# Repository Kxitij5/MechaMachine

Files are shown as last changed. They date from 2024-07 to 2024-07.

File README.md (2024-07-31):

# MechaMachine
## A real-time face tracking turret inspired by KillJoy, a character in the video game called Valorant.

A face tracking turret which tracks the faces of the people and aims for headshot. There are 2 versions of this project, one which uses open-cv and a python package built upon it, known as cvzone; the other one is a custom trained YOLOv5 model which differentiates between friend and enemy before shooting.

## Table Of Content
- [Installation](#installation)
- [Usage](#usage)
- [Contributing](#contributing)

## Installation
Follow the steps given below to setup this project on your machine/system.

### Prerequisites 
Ensure the following hardware, tools and software requirements:

#### Hardware
- 3D Print the printables given in the cad design directory.
- Arduino Uno R3 (or any other Microcontroller).
- Webcam with atleast 640*480 resolution.
- 2 130 DC motors rated 9v and above.
- 3 SG90s or MG90 Servo Motors. 
- LM2596 DC-DC Step Down Module.
- KY008 Laser Module.
- P30N06 N Channel MOSFET.
- 330ohm Resistor.
- FR107 Rectifier Diode.
- DC barrel jack.
- A few M-M, F-M, M-F Jumper Wires. 
- 12v 2amps DC Power Adaptor.

#### Tools and Fabrication Materials:
- Soldering Iron and wire.
- Heat Shrink Tubings.
- Screw Driver.
- M2, M2.5, M5 screws.
- Digital Multimeter.
- 3D Printer.

#### Software Requirements:
- Preferred Choice of Code Editor.
- Arduino IDE.
- Git.
- Python 3.7+.

### Clone the Repository 
Clone the repository to your local machine:
```bash
git clone https://github.com/Kxitij5/MechaMachine.git
cd MechaMachine
```
### Install Dependencies 
To install the python packages:
```bash
cd /MechaMachine_code
pip install -r requirements.txt
```

## Usage
The instructions to use the MechaMachine project:
### Hardware Connections and Schematics:
Refer the link to the [Hackster Project Website](have to give the link yet) to get the schematics and connections.

### Running the MechaMachine:
Connect the Arduino to the Host PC and change the com port in the code.
#### Uploading the Arduino Code:
- Go to MechaMachine_code directory.
- Open the Arduino_Code in the Arduino IDE.
- Upload the code to appropriate board.
#### To run the real-time version:
```bash
cd MechaMachine_code/
python MechaMachine.py
```
#### To run the trained version:
- Train your desired custom [YOLOv5 Model](https://colab.research.google.com/github/ultralytics/yolov5/blob/master/tutorial.ipynb).
- Download the model.
- Load it in the Trained_MechaMachine.py line number 6.
- Then do the following:
```bash
cd MechaMachine_code/
python Trained_MechaMachine.py
```

## Contributing
Follow these steps to contribute to [MechaMachine](https://github.com/Kxitij5/MechaMachine).

### Fork the Repository
Fork the repository on GitHub and clone your fork:
```bash
git clone https://github.com/your-username/MechaMachine.git
cd MechaMachine
```

### Create a Branch
Create a new branch for your feature or bugfix:
```bash
git checkout -b feature-branch
```

### Commit Changes 
Commit your changes with a descriptive commit message:
```bash
git commit -m "Add new feature"
```
### Push to the Branch
Push your changes to your fork:
```bash
git push origin feature-branch
```
### Open a Pull Request
Open a pull request on GitHub to merge your changes into the [MechaMachine](https://github.com/Kxitij5/MechaMachine) Repository.

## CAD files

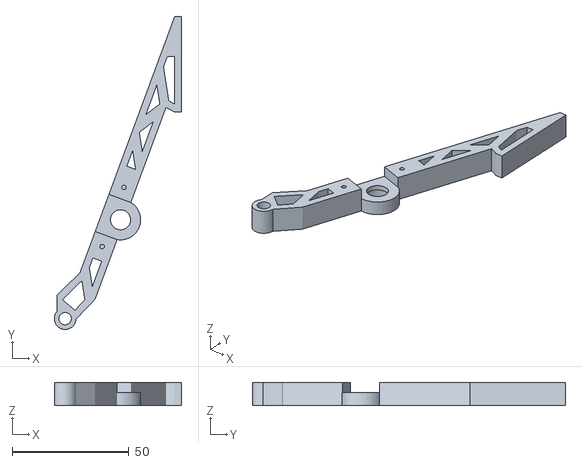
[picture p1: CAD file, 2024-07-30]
MechaMachine_cad_designs/Black/Long-Leg_black.stl
54.5 x 133.8 x 10.0

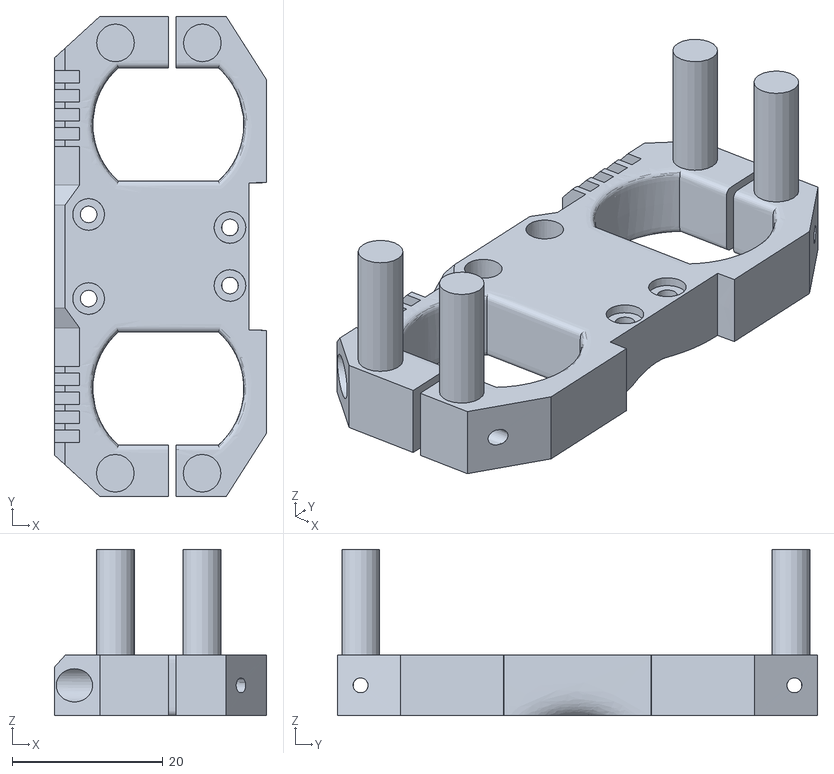
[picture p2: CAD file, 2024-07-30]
MechaMachine_cad_designs/Orange/Motor-holder_orange.stl
28.1 x 63.6 x 22.0

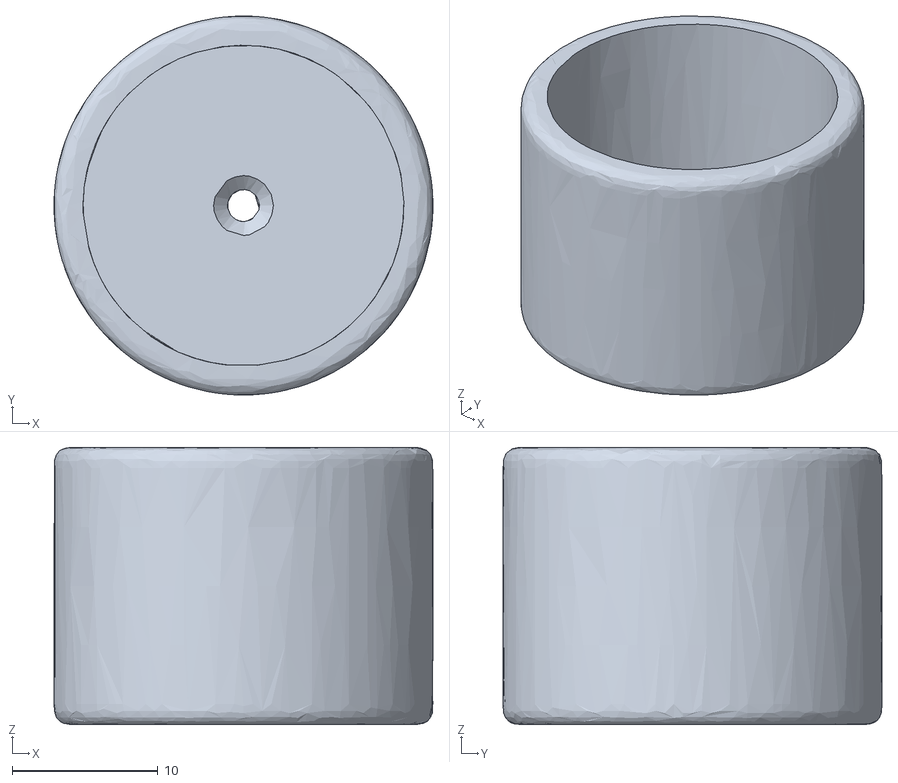
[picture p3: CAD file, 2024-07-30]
MechaMachine_cad_designs/Yellow/Roller-2_yellow.stl
26.0 x 26.0 x 19.0

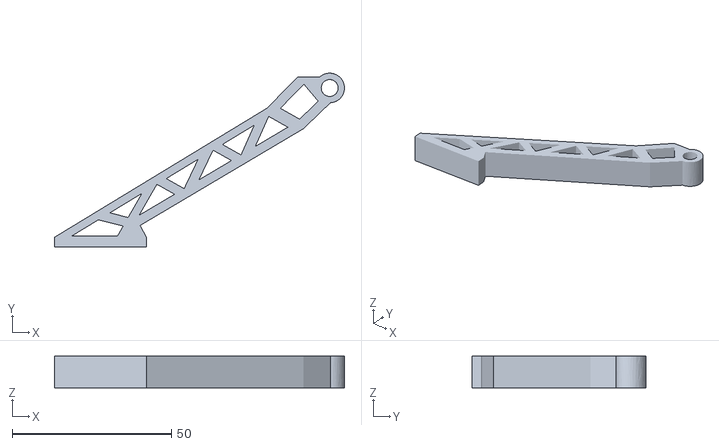
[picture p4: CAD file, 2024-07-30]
MechaMachine_cad_designs/Black/Short-Leg-1_black.stl
90.9 x 54.5 x 10.0

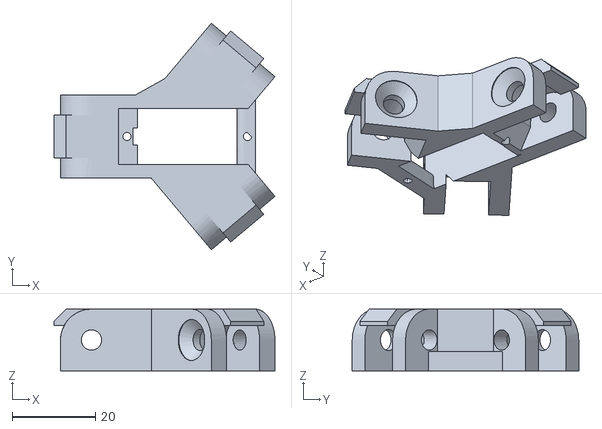
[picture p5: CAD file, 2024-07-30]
MechaMachine_cad_designs/Orange/SG90-Base_orange.stl
53.2 x 54.5 x 14.9

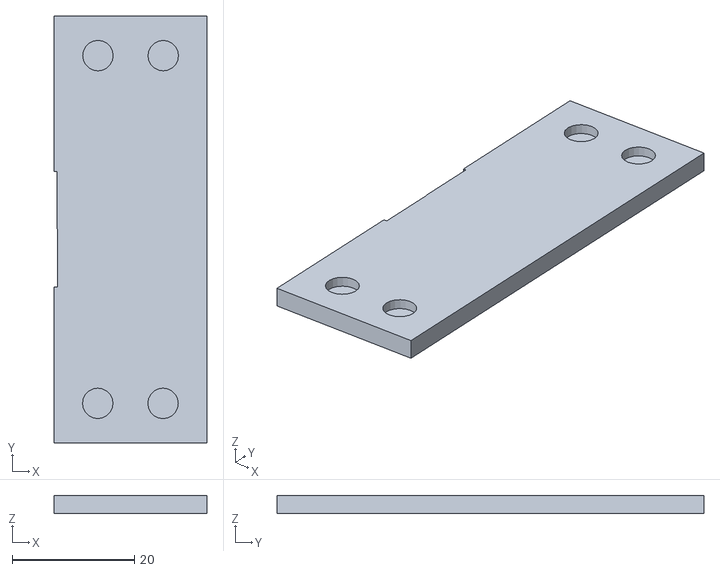
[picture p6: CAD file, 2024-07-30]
MechaMachine_cad_designs/Yellow/Plate_yellow.stl
25.0 x 70.0 x 3.00

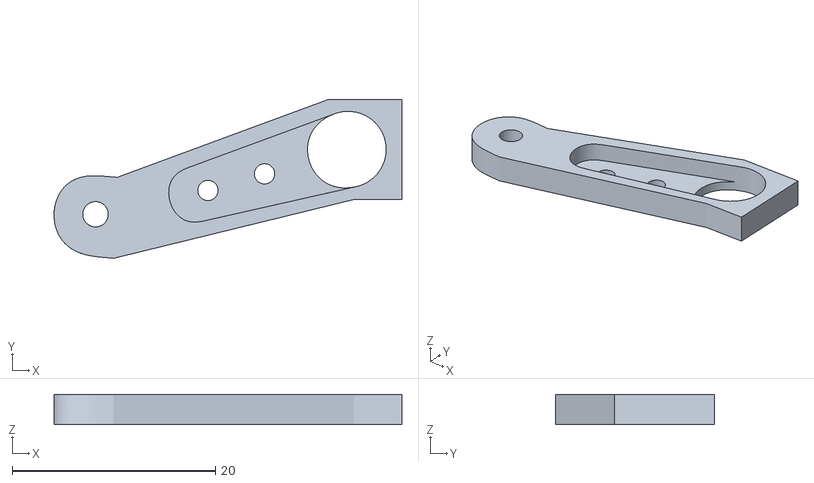
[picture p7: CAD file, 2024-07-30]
MechaMachine_cad_designs/Orange/Servo-Horn_orange.stl
34.3 x 15.6 x 2.96

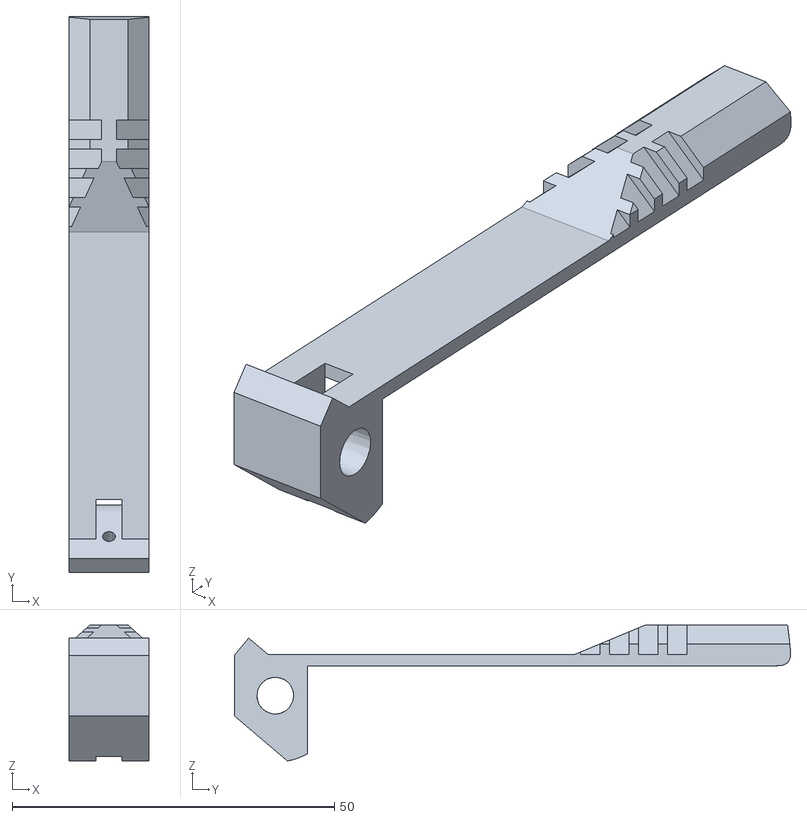
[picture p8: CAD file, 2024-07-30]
MechaMachine_cad_designs/Yellow/Magazine-Lock_yellow.stl
12.4 x 86.3 x 21.1

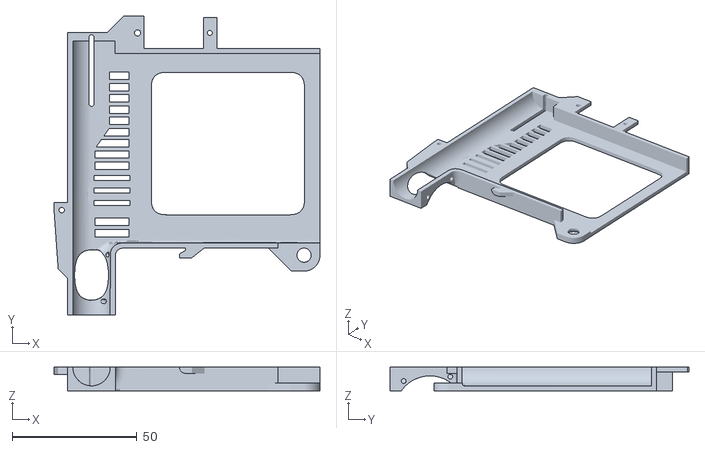
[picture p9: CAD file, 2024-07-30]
MechaMachine_cad_designs/Black/Barrel-R_black.stl
106.7 x 119.8 x 9.50

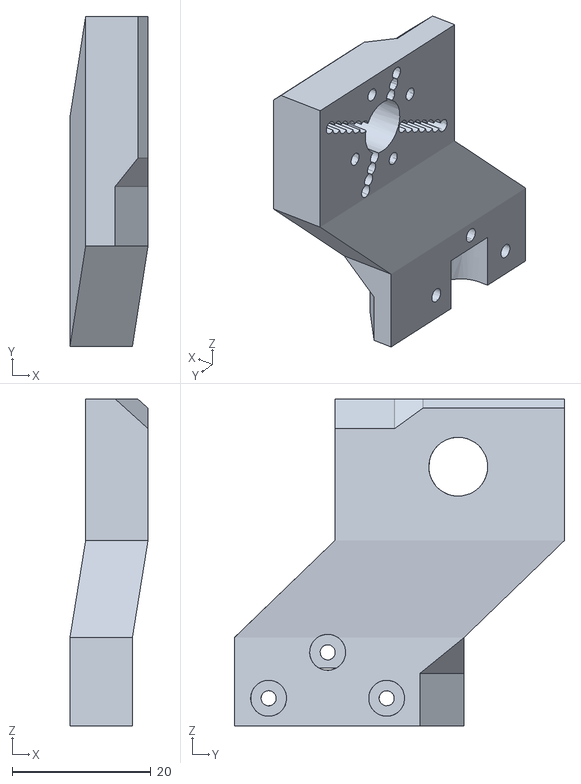
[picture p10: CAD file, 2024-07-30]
MechaMachine_cad_designs/Yellow/Neck_yellow.stl
11.3 x 47.6 x 47.1

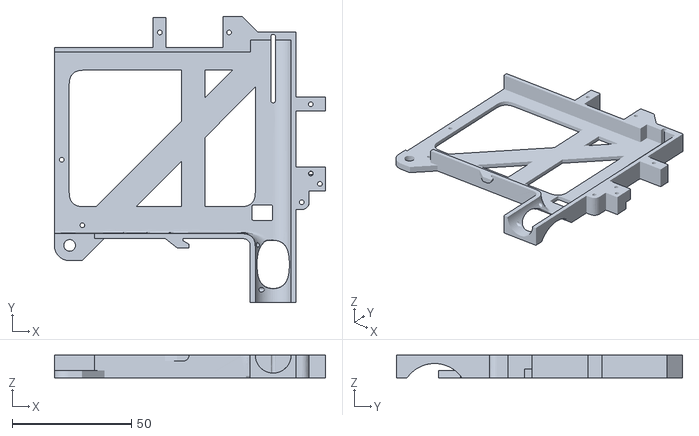
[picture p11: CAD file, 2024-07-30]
MechaMachine_cad_designs/Black/Barrel-L_black.stl
113.6 x 119.8 x 9.50

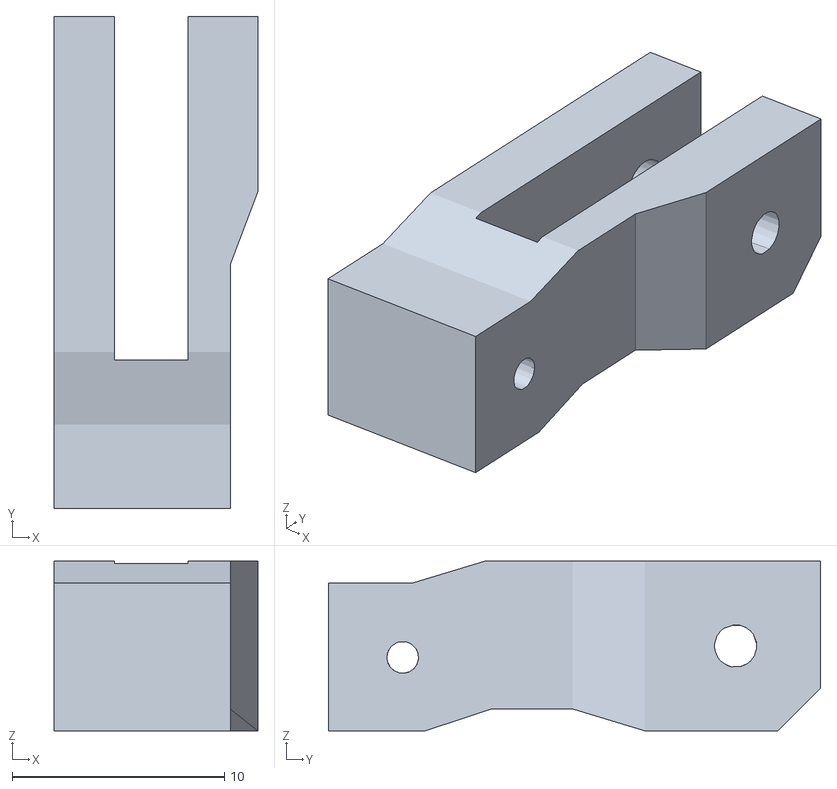
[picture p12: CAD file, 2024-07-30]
MechaMachine_cad_designs/Yellow/Recoil-Arm_yellow.stl
9.60 x 23.2 x 8.00

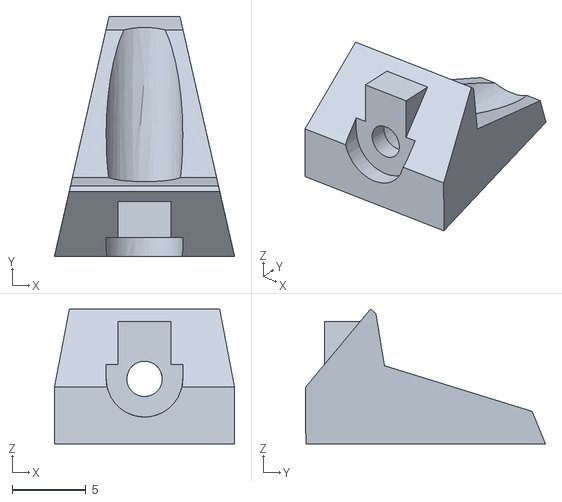
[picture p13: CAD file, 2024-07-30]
MechaMachine_cad_designs/Yellow/Band-Lock_yellow.stl
12.3 x 16.3 x 9.17

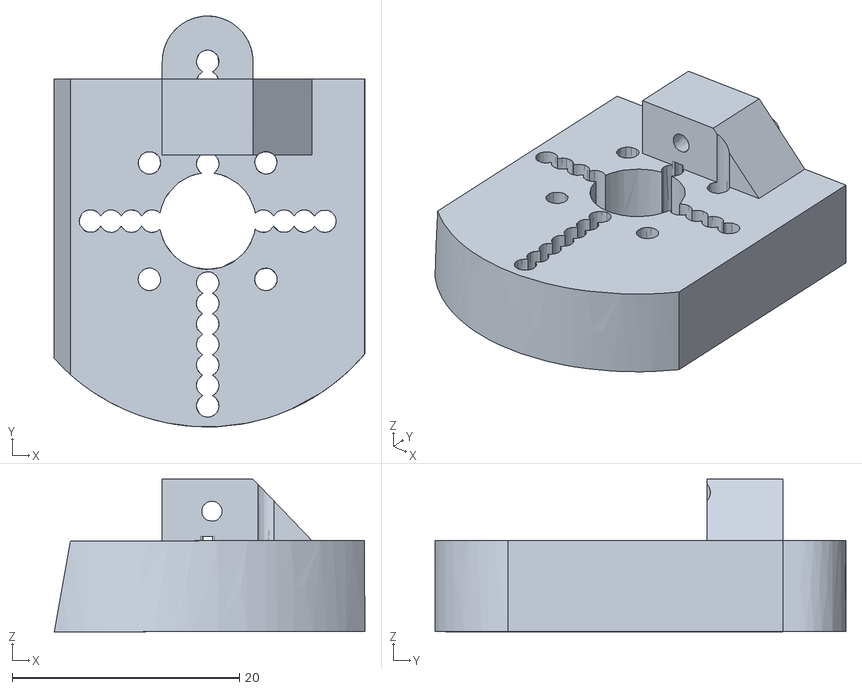
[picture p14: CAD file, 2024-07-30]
MechaMachine_cad_designs/Yellow/Rotator_yellow.stl
27.3 x 36.2 x 13.5

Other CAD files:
MechaMachine_cad_designs/Black/Short-Leg-2_black.stl
MechaMachine_cad_designs/Yellow/Roller-1_yellow.stl

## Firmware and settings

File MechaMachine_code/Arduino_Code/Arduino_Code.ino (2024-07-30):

#include<Servo.h>

//------- info for serial communication-----
// consider changing byte to int, cuz byte will truncate the data of x and y coordinates to lie in the range of (0,255)
const int buffer_size = 6;
int input_buffer[buffer_size];
const int startMarker = 999;
const int endMarker = 998;
boolean data_rcvd = false;


//------- info for servos ---------
Servo pan, tilt, trigger;
int width = 640, height = 480;  // resolution of the video
int xpos = 90, ypos = 90;  // variables for movement angles of pan -> xpos, tilt -> ypos
const int angle = 1; // increment or decrement to the xpos and ypos to make the servos move




//----- info for arming MehcaMachine -------
const int arm_motor = 7;
boolean is_armed = false;

//----- info for firing and reloading ------
boolean is_firing = false;
boolean reloading = false;
boolean can_fire = false;
const int laser = 13;

unsigned long fire_start_time = 0;
unsigned long fire_current_time = 0;
const long fire_time = 150;

unsigned long reload_start_time = 0;
unsigned long reload_current_time = 0;
const long reload_time = 2 * fire_time;

const int trigger_pulled = 180;    // Angle of the trigger servo when at rest
const int trigger_pushed = 125;    // Angle of the trigger servo when pushed

void setup() {
  // put your setup code here, to run once:
  pan.attach(9);
  pan.write(xpos);
  tilt.attach(10);
  tilt.write(ypos);
  trigger.attach(11);
  trigger.write(trigger_pulled);
  pinMode(arm_motor,OUTPUT);
  pinMode(laser,OUTPUT);
  Serial.begin(9600);
}

void loop() {
  // put your main code here, to run repeatedly:
  digitalWrite(laser,HIGH);
  getData();
  arm();
  if(data_rcvd){
    track_face();
    set_trigger();
    arm();
    fire();
    }
  
  
}

void getData(){
  // input from serial communication will be of this pattern:
//  [startMarker, x_coordinate, y_coordinate, arm_motor, fire, endMarker]
// startMarker  -> this variable indicates the start of the data being sent by the python code.
// x_coordinate -> this indicates the x coordinates of the face being sent by the python code.
// y_coordinate -> this indicates the y coordinates of the face being sent by the python code.
// arm_motor    -> this indicates whether MechaMachine should be armed or not
// fire         -> this indicates whether MechaMachine should shoot or not
// endMarker -> this is the end marker of the data being sent by the computer.
//  com.Get(input_buffer);
if (Serial.available() > 0)
  {
    data_rcvd = true;
    if (Serial.read() == 'S')
    {
      input_buffer[0] = Serial.parseInt();  
      if (Serial.read() == 'X')
        input_buffer[1] = Serial.parseInt();
        if (Serial.read() == 'Y')
          input_buffer[2] = Serial.parseInt();
          if (Serial.read() == 'A')
            input_buffer[3] = Serial.parseInt();
            if (Serial.read() == 'F')
              input_buffer[4] = Serial.parseInt();
              if (Serial.read() == 'E')
                input_buffer[5] = Serial.parseInt();
        
    }
//  if(input_buffer[0] == startMarker && input_buffer[5] == endMarker){
//    data_rcvd = true;
//    }
  }  else{
    data_rcvd = false;
    }
  

}


void track_face(){
  int face_x, face_y;
//  check if the conversion of bytes to int happens automatically or change the variable face_x and face_y to byte aswell and test out again!!
  face_x = input_buffer[1];
  face_y = input_buffer[2];
  // if the servo degree is outside its range of the rectangle perimeter of 30 pixels
  if (face_x > width / 2 + 30)
      xpos += angle;
    if (face_x < width / 2 - 30)
      xpos -= angle;
    if (face_y < height / 2 + 30)
      ypos += angle;
    if (face_y > height / 2 - 30)
      ypos -= angle;

      
//A better acceleration based movement of the servos:
/* const int xThreshhold[] = {96, 192, 290, 446, 542, 640};
 *  const int yThreshhold[] = {70, 140, 210, 340, 410, 480};
 *  
 *  const int xSteps[] = {-3, -2, -1, 1, 2, 3};
 *  const int ySteps[] = {3, 2, 1, -1, -2, -3};
 *  
 *  for(int i = 0 ; i < sizeof(xThreshold); i++){
 *    if(face_x < xThreshold[i]){
 *      xpos += xSteps[i];
 *    }
 *  }
 *  
 *  for(int i = 0 ; i < sizeof(yThreshold); i++){
 *    if(face_y < yThreshold[i]){
 *      ypos += ySteps[i];
 *    }
 *    
 *    
 *  }
 */

    
    if (xpos >= 180)
      xpos = 180;
    else if (xpos <= 0)
      xpos = 0;
    if (ypos >= 180)
      ypos = 180;
    else if (ypos <= 0)
      ypos = 0;

    pan.write(xpos);
    tilt.write(ypos);




}


void arm(){
  if(input_buffer[3] == 1){
    digitalWrite(arm_motor,HIGH);
    is_armed = true;
    }
  else{
    digitalWrite(arm_motor,LOW);
    is_armed = false;
    }
}


void set_trigger(){
   if(input_buffer[4] == 1){
    if(!is_firing && !reloading){
      can_fire = true;
      }
    }
   else{
    can_fire = false;
    }
}


void fire(){
    if(can_fire && !is_firing && is_armed){
      fire_start_time = millis();
      reload_start_time = millis();
      is_firing = true;
    }
    fire_current_time = millis();
    reload_current_time = millis();

    if(is_firing && fire_current_time - fire_start_time < fire_time){
      trigger.write(trigger_pushed);
      }
    else if(is_firing && fire_current_time - fire_start_time < reload_time){
      trigger.write(trigger_pulled);
      }
    else if(is_firing && reload_current_time - reload_start_time > reload_time){
      is_firing = false;
      }
}

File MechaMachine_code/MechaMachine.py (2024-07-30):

import cv2
from cvzone.FaceDetectionModule import FaceDetector
import serial,time

#Initialize face detector from the cvzone package 
detector = FaceDetector(minDetectionCon=0.7, modelSelection=0)

#Initialize the serial communication with the arduino; change com based on the connected com port
ArduinoSerial=serial.Serial('com4',9600,timeout=0.1)

#Initialize the camera; change index based on the connected camera 
cap = cv2.VideoCapture(1)


#Initialize the variable to be sent to the arduino
# The firing square is 60px wide and high 
tolerance_x = 640//2-30
tolerance_y = 480//2-30
tolerance_w = 640//2+30
tolerance_h = 480//2+30

# The arming square is 25px wider and higher than the firing square
arming_tolerance_x = tolerance_x - 25
arming_tolerance_y = tolerance_y - 25
arming_tolerance_w = tolerance_w + 25
arming_tolerance_h = tolerance_h + 25
startMarker = 999
endMarker = 998
arm_motor = 0 
fire = 0
in_box_time = 0

# Start Checking for the faces 
while True:
    success, img = cap.read()
    img = cv2.flip(img,1)
    img, faces = detector.findFaces(img, draw=False)
    #If a lot of faces are found then take the first occurence of the face in the array
    if faces:
        face = faces[0]
        #Get the coordinates of the face
        x, y, w, h = face['bbox']
        cor_x = x+w//2
        cor_y = y+h//4
        
        # Check if the coordinates are inside the amring range of the MechaMachine
        if cor_x in range(arming_tolerance_x, arming_tolerance_w) and cor_y in range(arming_tolerance_y, arming_tolerance_h):
            arm_motor = 1
        else:
            arm_motor = 0
            
        # Check if the coordinates are inside the firing range of MechaMachine
        if cor_x in range(tolerance_x, tolerance_w) and cor_y in range(tolerance_y, tolerance_h):
            in_box_time = int(time.time() * 1000)
            if in_box_time > 500:
                fire = 1
        else: 
            in_box_time = 0 
            fire = 0
        
        #Prepare the string to be sent to the arduino
        string='S{0:d}X{1:d}Y{2:d}A{3:d}F{4:d}E{5:d}'.format((startMarker),(cor_x),(cor_y),(arm_motor),(fire),(endMarker))
        print(string)
        
        
        #Data structure sent to the arduino:
        # {S999X100Y100A0F0E998} 
        # S999 = Start Marker
        # X100 = X coordinate of the face
        # Y100 = Y coordinate of the face
        # A0 = Arm Motor (0 = Off, 1 = On)
        # F0 = Fire (0 = Off, 1 = On)
        # E998 = End Marker
        
        
        
        
        #Send the data to the aruino
        ArduinoSerial.write(string.encode('utf-8'))
        
        #Mark the face on the display
        cv2.circle(img, (cor_x,cor_y),2,(255,255,255),2)
        cv2.rectangle(img,(x,y),(x+w,y+h),(0,0,255),3)
        
    # This the constraint rectangle. 30 is the tolerable pixel length.
    cv2.rectangle(img,(tolerance_x, tolerance_y),(tolerance_w,tolerance_h),(0,0,0),3)
    cv2.rectangle(img,(arming_tolerance_x, arming_tolerance_y),(arming_tolerance_w, arming_tolerance_h),(255,0,0),3)
    
    cv2.imshow("MechaMachine",img)
    # press q to Quit
    if cv2.waitKey(1)&0xFF== ord('q'):
        break
cap.release()
cv2.destroyAllWindows()

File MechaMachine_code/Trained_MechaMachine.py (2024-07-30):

import cv2
import torch
import serial,time

# Load YOLOv5 model
model = torch.hub.load(r"<path/to/the/git/cloned/yolov5/repository>", "custom", path=r"<path/to/your/quantized/model>", source="local",device = 'cpu')

# Specify the confidence threshold
confidence_threshold = 0.5

# Initialize the webcam; change the index based on the index of the camera
cap = cv2.VideoCapture(0)

# Initialize the arduino UNO; change the port based on the connected com port
ArduinoSerial=serial.Serial('com4',9600,timeout=0.1)

# Initialize the variables for the string to be sent to arduino
tolerance_x = 640//2-30
tolerance_y = 480//2-30
tolerance_w = 640//2+30
tolerance_h = 480//2+30
arming_tolerance_x = tolerance_x - 25
arming_tolerance_y = tolerance_y - 25
arming_tolerance_w = tolerance_w + 25
arming_tolerance_h = tolerance_h + 25
startMarker = 999
endMarker = 998
arm_motor = 0 
fire = 0
in_box_time = 0

# Check if the webcam is opened correctly
if not cap.isOpened():
    print("Error: Could not open webcam.")
    exit()

try:
    while True:
        
        ret, frame = cap.read()
        cv2.flip(frame,1)
        if not ret:
            print("Error: Could not read frame.")
            break

        # Perform inference
        results = model(frame)

        # Process results
        for result in results.xyxy[0]:  # xyxy format: (x1, y1, x2, y2, confidence, class)
            x1, y1, x2, y2, confidence, cls = result
            
            #Check for confidence
            if confidence > confidence_threshold:
                
                #Check if it is enemy? 0 -> enemy 1 -> friend; change the class based on the model.
                if int(cls)==1:
                    
                    #convert all the values from YOLOv5 inference to int for ease of use.
                    x1 = int(x1)
                    y1 = int(y1)
                    x2 = int(x2)
                    y2 = int(y2)
                    
                    # Calculate the center or the point on the face to be tracked.
                    cor_x = (x1+x2)//2
                    cor_y = (y1+y2)//2
                                        
                    #Check if the face coordinates are incide the range of arming square
                    if cor_x in range(arming_tolerance_x, arming_tolerance_w) and cor_y in range(arming_tolerance_y, arming_tolerance_h):
                        arm_motor = 1
                    else:
                        arm_motor = 0
                        
                    #Check if the face coordinates are in in tolerence zone for firing 
                    if cor_x in range(tolerance_x, tolerance_w) and cor_y in range(tolerance_y, tolerance_h):
                        in_box_time = int(time.time() * 1000)
                        if in_box_time > 500:
                            fire = 1
                    else: 
                        in_box_time = 0 
                        fire = 0
                        
                    #Prepare the string to send to the Arduino
                    string='S{0:d}X{1:d}Y{2:d}A{3:d}F{4:d}E{5:d}'.format((startMarker),(cor_x),(cor_y),(arm_motor),(fire),(endMarker))
                    print(string)
                    
                    #Send the string to the Arduino
                    ArduinoSerial.write(string.encode('utf-8'))
                    
                    #Mark the Bounding box of the face and the point blank
                    cv2.circle(frame, (cor_x,cor_y),2,(255,255,255),2)
                    cv2.rectangle(frame,(x1,y1),(x2,y2),(0,0,255),3)
                    
                    
                else:
                    #If a friend is detected then don't shoot.
                    #convert all the values from YOLOv5 inference to int for ease of use.
                    x1 = int(x1)
                    y1 = int(y1)
                    x2 = int(x2)
                    y2 = int(y2)
                    #Calculate the center or the point on the face to be tracked.
                    cor_x = (x1+x2)//2
                    cor_y = (y1+y2)//2
                    
                    print("Friend Detected Shooting Halted.")
                    
                    #Mark the Bounding box of the face and the point blank
                    cv2.circle(frame, (cor_x,cor_y),2,(255,255,255),2)
                    cv2.rectangle(frame,(x1,y1),(x2,y2),(0,255,0),3)
                    
                    
                    
                
                
        #Display the resulting frame
        cv2.imshow('MechaMachine', frame)

        #Press q to exit
        if cv2.waitKey(1) & 0xFF == ord('q'):
            break

except KeyboardInterrupt:
    print("Interrupted by user")

finally:
    cap.release()
    cv2.destroyAllWindows()
